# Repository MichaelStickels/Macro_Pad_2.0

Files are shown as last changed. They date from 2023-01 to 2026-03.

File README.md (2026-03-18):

# Macro Pad 2.0

DIY custom macro keypad and [Deej](https://github.com/omriharel/deej) volume control board with RGB based on the Seeed Studio XIAO RP2040 and CircuitPython.

<div align="center">
  <kbd>
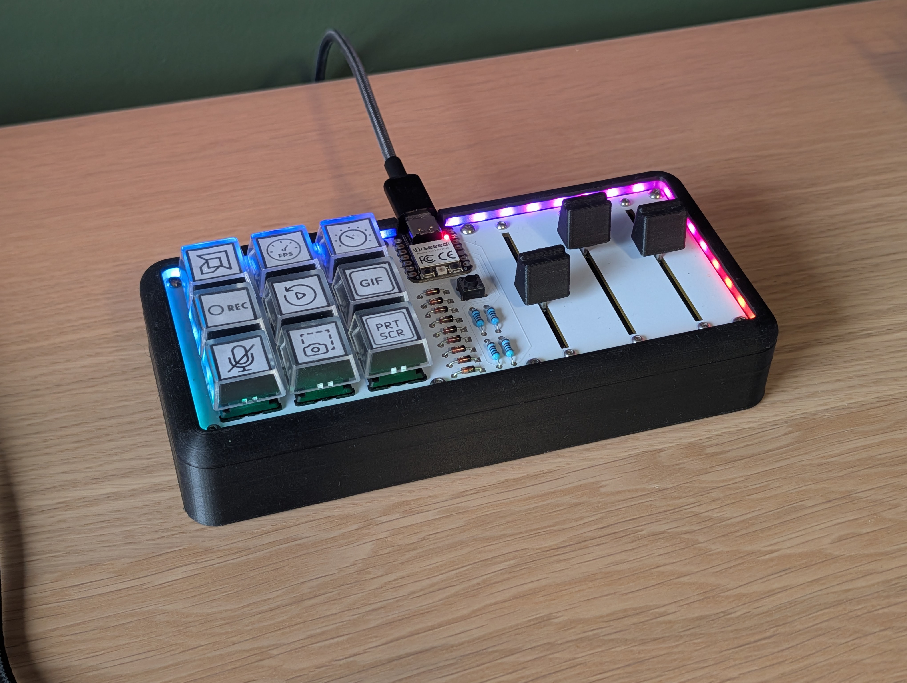
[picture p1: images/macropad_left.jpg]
    
  </kbd>
</div>

## Description

After really enjoying my [first DIY macro keypad](https://github.com/MichaelStickels/Macro_Keypad), I set out to create a second iteration of my own unique design that incorporated even more features. Mainly, I wanted to combine custom macro functionality with slide potentiometers for per-app volume control with Deej. This macro pad prioritizes looks rather than targeting the lowest cost or easiest assembly. The keyswitches are frame-mounted through the PCB so require hand wiring on the back, and the special side lit LED strip for the RGB is a bit spendy. But I am very happy with how it turned out, and it looks great on my desk.

### Features

- 9 fully programmable custom macro keys
- 3 volume sliders for use with Deej
- Fully customizable RGB and onboard button
- Easily change settings with almost any text editor
- USB C interface
- Mechanical keyswitches
- No driver needed
- Open source

### Built with

- CircuitPython
- Adafruit NeoPixel
- Adafruit MatrixKeypad
- Deej
- Love

## Photos

Some more photos of the project and the build process.

<div align="center">
  <kbd>
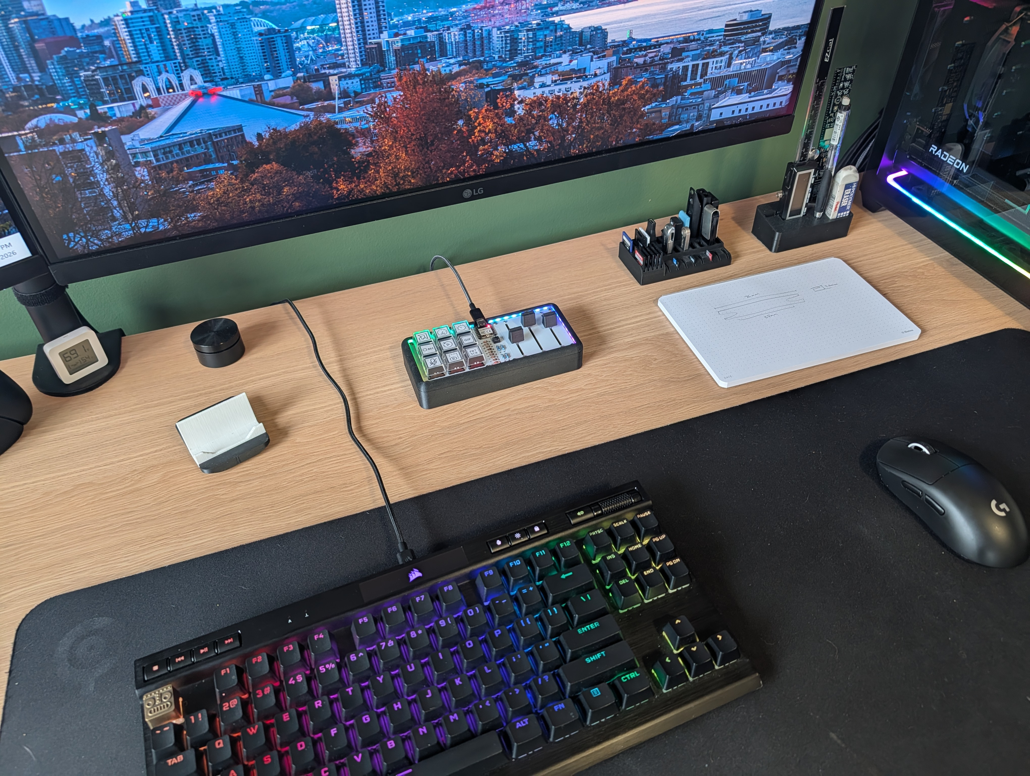
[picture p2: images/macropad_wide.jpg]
    
  </kbd>
 <!--  caption of what is in this photo -->
</div>

<div align="center">
  <kbd>
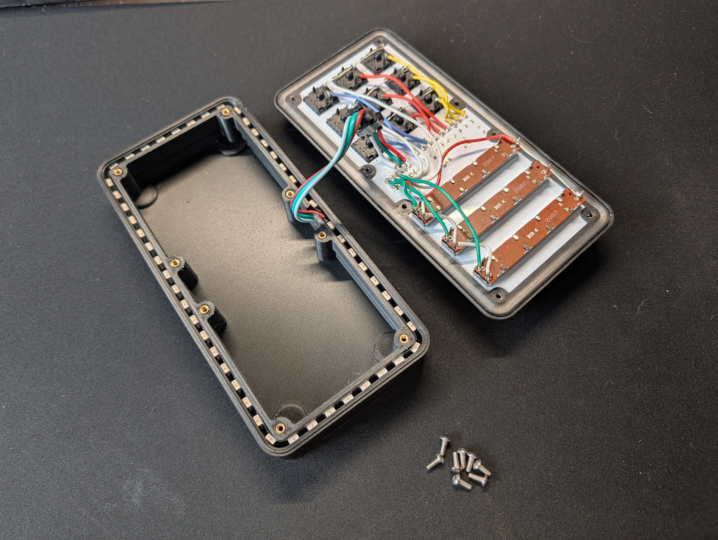
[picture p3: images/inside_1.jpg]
    
  </kbd>
 <!--  caption of what is in this photo -->
</div>

<div align="center">
  <kbd>
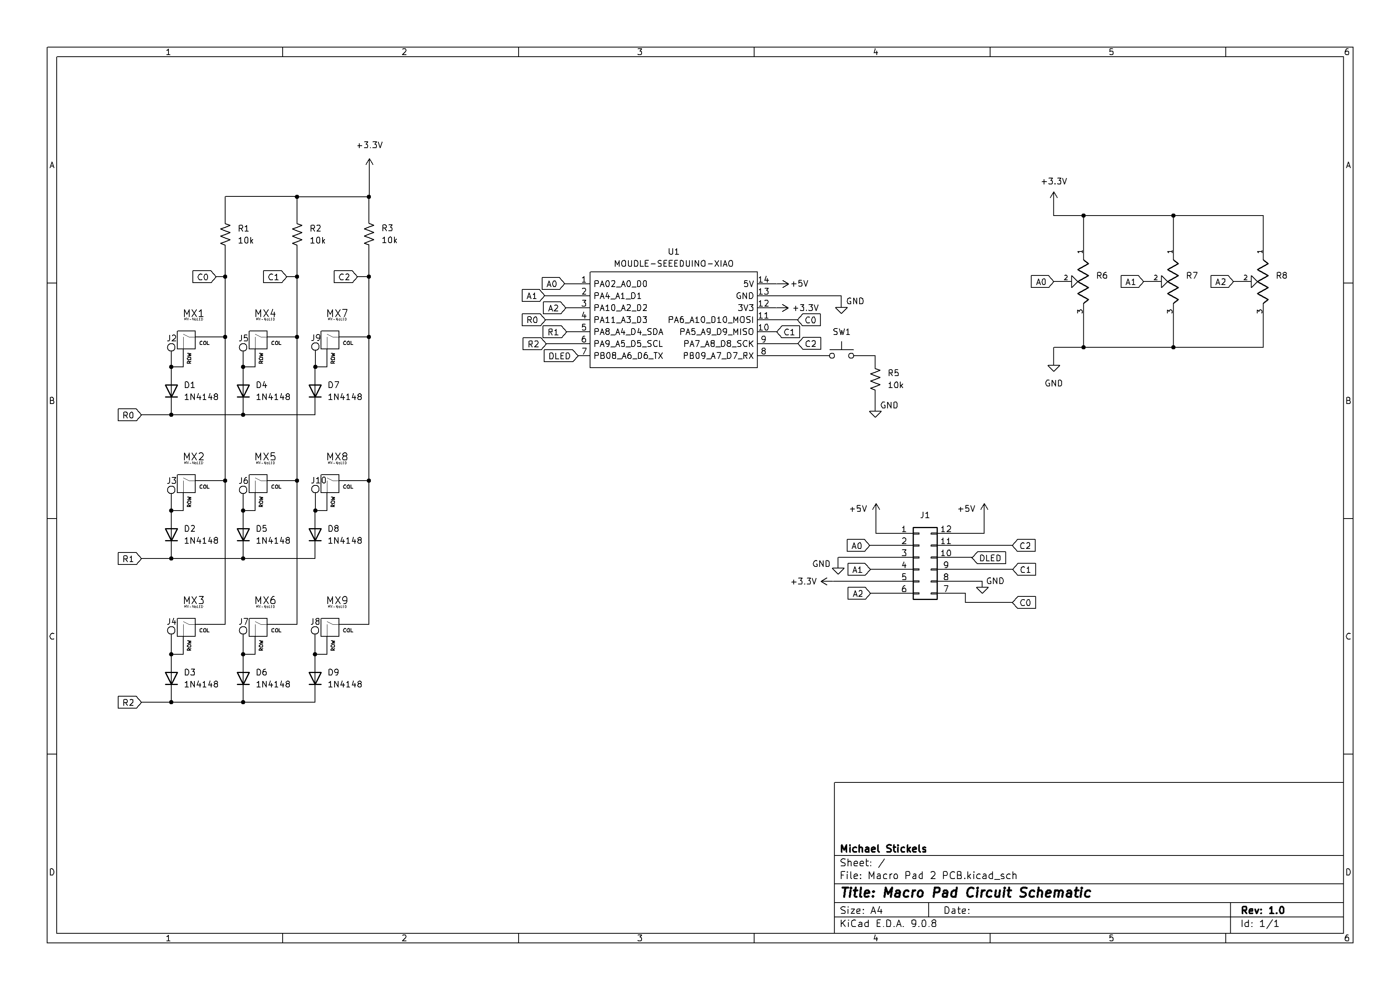
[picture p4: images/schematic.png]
    
  </kbd>
 <!--  caption of what is in this photo -->
</div>

## Building One Yourself

#### Here's what you'll need:
1. Custom PCB from an online supplier
2. 3D printed case
3. All parts listed on the BOM below
4. One USB-C cable
5. Basic soldering tools

### Custom PCB

PCB Gerber files are included in the release. Simply upload the whole .zip to the custom PCB manufacturer of your choice to order one for yourself (like JLPCB). This project only needs a very basic 2 layer PCB, I recommend white to show off the RGB. Make sure you choose the 'remove mark' or equivilent option to make sure they don't print an order number on the front fo your PCBs.

### 3D Printed Case

The case top uses translucent filament as a light pipe for the LEDs. At this revision, the design requires a multi-material printer. If you don't want to implement the RGB, you can print it all in one color on almost any printer. STL, 3MF, and F3D files are included for all parts.
<div align="center">
  <kbd>
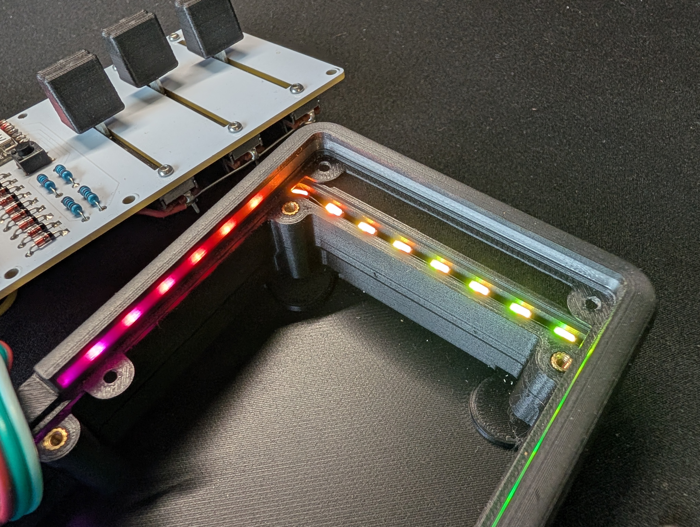
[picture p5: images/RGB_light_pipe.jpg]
    
  </kbd>
 <!--  caption of what is in this photo -->
</div>

### Bill Of Materials  
[Here](https://www.digikey.com/short/9nwmrv4t) is a DigiKey cart with all electronic components ready to order.

| Quantity | Item | DigiKey Link |
|---|---|---|
| 1 | MacroPad PCB | |
| 1 | Seeed Studio XIAO RP2040 | [1597-102010428-ND](https://www.digikey.com/en/products/detail/seeed-technology-co-ltd/102010428/14672129) |
| 9 | Cherry MX Style Keyswitches | [CH196-ND](https://www.digikey.com/en/products/detail/cherry-americas-llc/MX1A-E1NN/40084) |
| 9 | Keycaps | [1528-5662-ND](https://www.digikey.com/en/products/detail/adafruit-industries-llc/5662/18716469) |
| 3 | 45mm 10k Slide Potentiometers | [PTA4553-2015CPB103-ND](https://www.digikey.com/en/products/detail/bourns-inc/PTA4553-2015CPB103/3781213) |
| 1 | 6x6mm Tactile Push Button | [450-1650-ND](https://www.digikey.com/en/products/detail/te-connectivity-alcoswitch-switches/1825910-6/1632536) |
| 4 | 10kΩ Resistors | [MFP-25BRD52-10K](https://www.digikey.com/en/products/detail/yageo/MFP-25BRD52-10K/2058797) |
| 9 | 1N4148 Diodes | [1N4148FS-ND](https://www.digikey.com/en/products/detail/onsemi/1N4148/458603) |
| 1 | Side Lit 5v RGB LED Strip | [1528-2499-ND](https://www.digikey.com/en/products/detail/adafruit-industries-llc/3634/8019479) |
| 1 | 3D Printed Case | |
| 8 | M2.5 Screws | |
| 8 | M2.5 Heat-set Inserts | |
| 6 | M2 Screws (to mount pots) | |
| | Some small wire for hand soldering keyswitches | |

### Assembly

Solder the RP2040, resistors, diodes, and button to the front of the board. 3D-printable bend guides are included to get clean consistent shapes on all the diodes and resistors.

Then install the keyswitches and pots, and flip it over to hand wire the back.
The PCB features labeled pads on the back to connect the keyswitches, potentiometers, and RGB strip. Hand wiring these is a little tricky but results in a very clean look on the front.
<div align="center">
  <kbd>
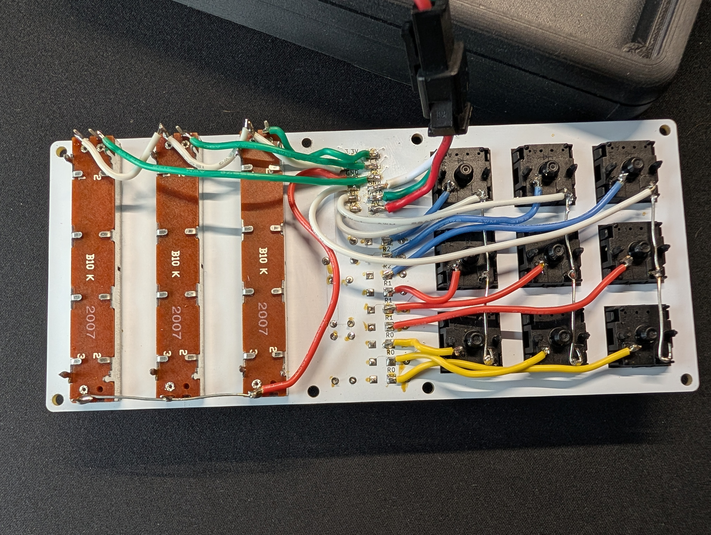
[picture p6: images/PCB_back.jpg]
    
  </kbd>
 <!--  caption of what is in this photo -->
</div>

### Software

Once soldered up, install the [CircuitPython bootloader](https://circuitpython.org/board/seeeduino_xiao_rp2040/) onto the RP2040 using [these instructions](https://wiki.seeedstudio.com/XIAO-RP2040-with-CircuitPython/).

Then copy the entire contents of the firmware folder to the CIRCUITPYTHON drive. This includes the example configuration and the necessary external libraries.

Press the reset button or unplug and replug the RP2040 and your Macro Pad will be up and running!

For the volume sliders to work you will need to install and configure [Deej](https://github.com/omriharel/deej) using [these instructions](https://github.com/omriharel/deej?tab=readme-ov-file#how-to-run). My Deej config.yaml is included as an example.

### Configure

The Macro Pad can be easily configured using any text editor, including Notepad.

To keep your file explorer tidy, the Macro Pad does not show up as a storage device by default. To access the drive, hold the 6x6mm pushbutton down while the board boots (either by pressing the reset button or while plugging in).

It will show up on your computer as a new storage drive named MACROPAD. To configure the Pad, edit conig.py in your favorite text editor. In config.py you can edit the macro for each of the 9 keyswitches as well as the RGB mode, color, and brightness. More detailed instructions are in the file.

### Usage

WIP

### Troubleshooting

WIP

## Back matter

### Acknowledgements

Inspiration from the following projects:
* [ocreeb-12](https://github.com/sb-ocr/ocreeb-12/tree/main)
* [DuckyPad](https://github.com/dekuNukem/duckyPad)

README adapted from [TINY README](https://gist.github.com/noperator/4eba8fae61a23dc6cb1fa8fbb9122d45)

Huge shout-out to the [Deej](https://github.com/omriharel/deej) project, it's an awesome piece of software.

### See also

- [Getting Started with Seeed Studio XIAO RP2040](https://wiki.seeedstudio.com/XIAO-RP2040/)
- My first [Macro Keypad](https://github.com/MichaelStickels/Macro_Keypad)

### To-do

- [x] Implement Deej serial sender in CircuitPython
- [x] Implement configuration file
- [x] Test and refine 3D printed enclosure
- [x] Implement configurable RGB
- [ ] Implement push button to do... something?
- [ ] Expand built-in RGB options
- [ ] Revise case to work on single material printers
- [ ] DIY dye sublimation keycaps
- [ ] Create and publish Deej library for CircuitPython

### License

This project is licensed under the [GPL-3.0 License](LICENSE.md).

### Support

Like what I do?  
<a href="https://www.buymeacoffee.com/michaelstickels" target="_blank">Buy Me A Coffee</a>

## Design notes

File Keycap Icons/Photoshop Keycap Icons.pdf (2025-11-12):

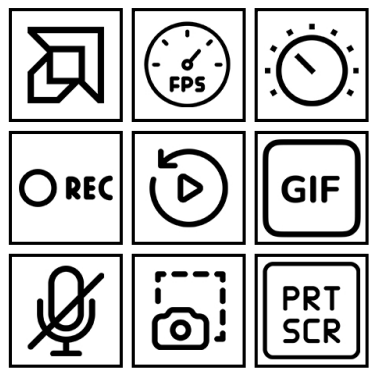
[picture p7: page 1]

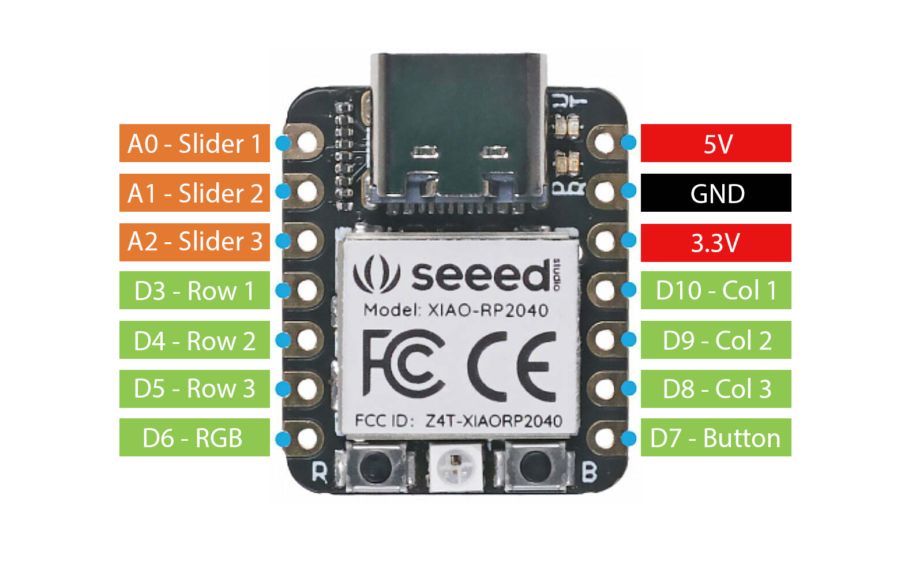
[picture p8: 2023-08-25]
images/pinout.png

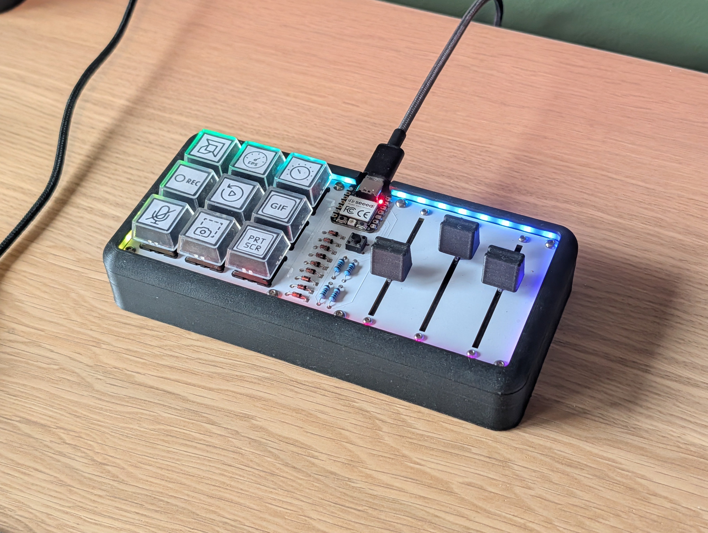
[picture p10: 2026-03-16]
images/macropad_right.jpg

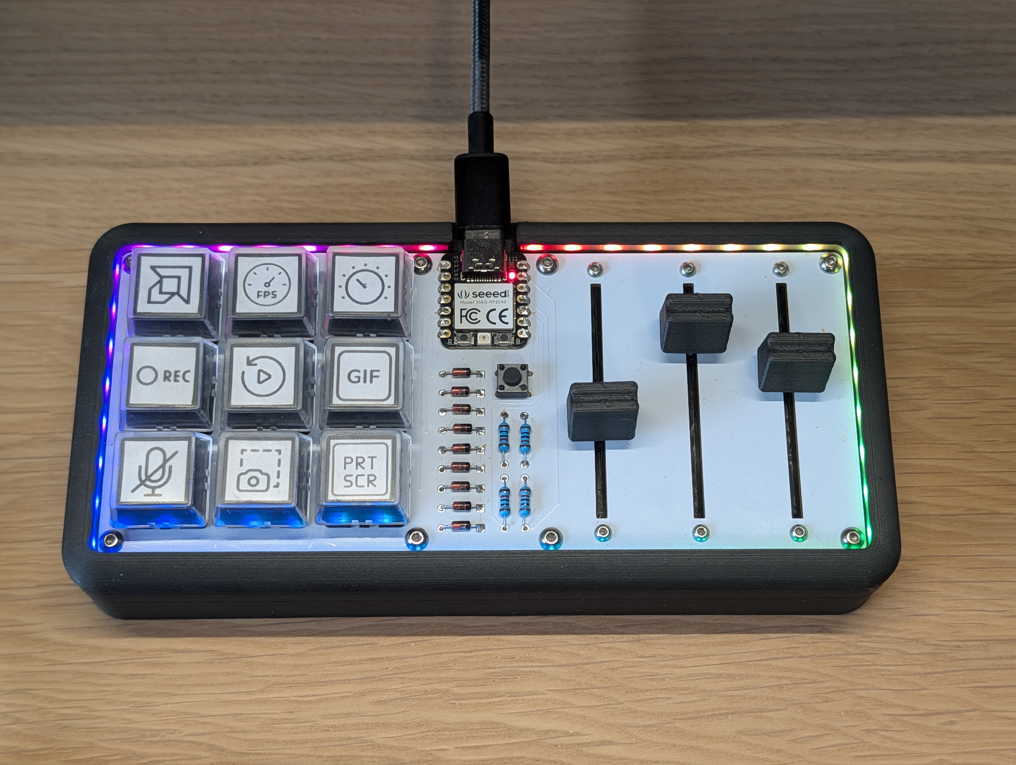
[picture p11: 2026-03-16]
images/macropad_top.jpg

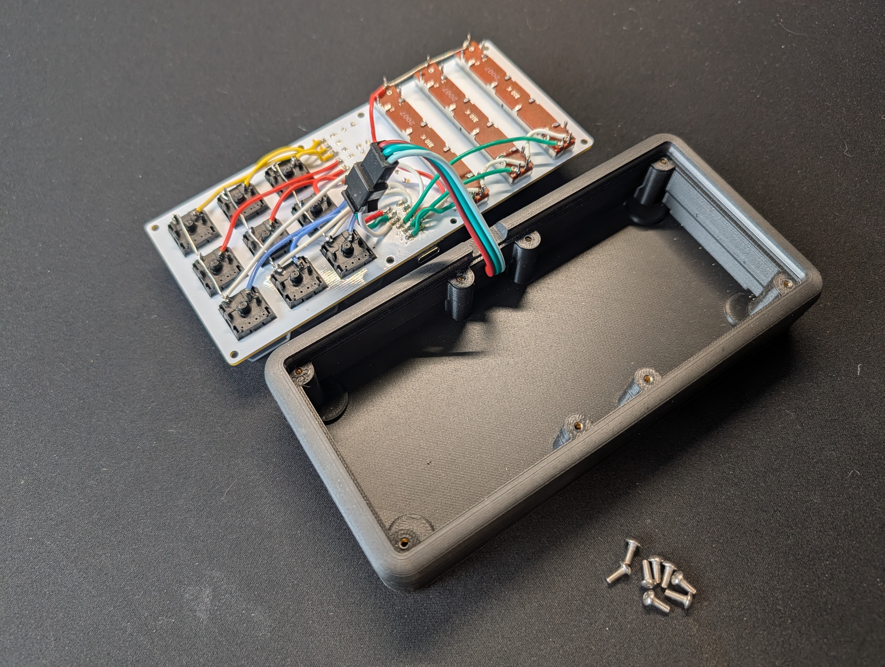
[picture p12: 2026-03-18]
images/inside_2.jpg

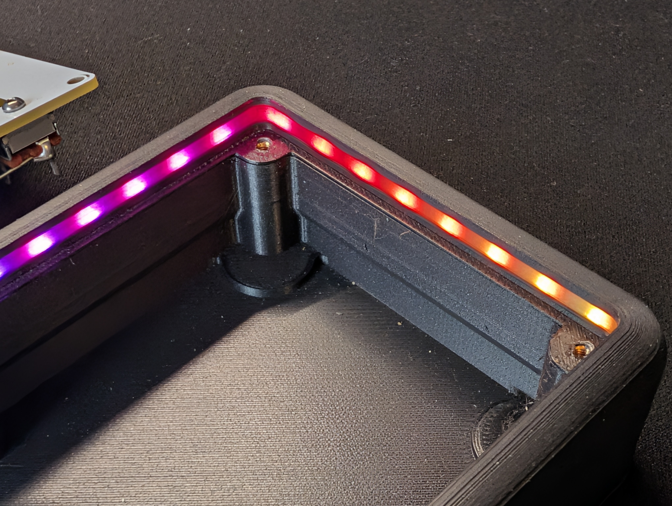
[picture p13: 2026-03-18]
images/RGB_closeup.jpg

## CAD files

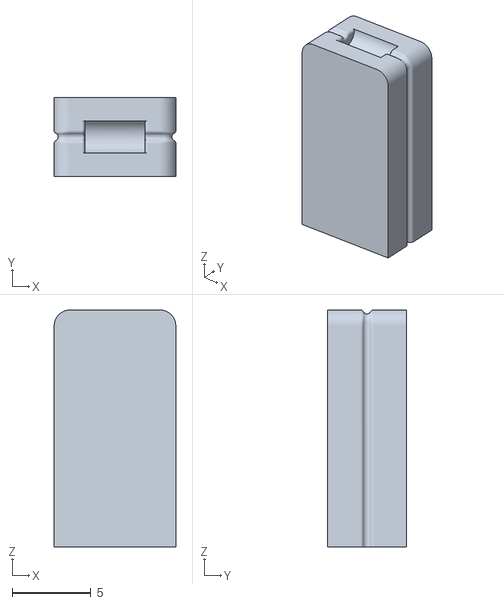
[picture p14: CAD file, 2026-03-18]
3D Print Files/Diode Bend Guide.stl
7.70 x 5.00 x 15.0

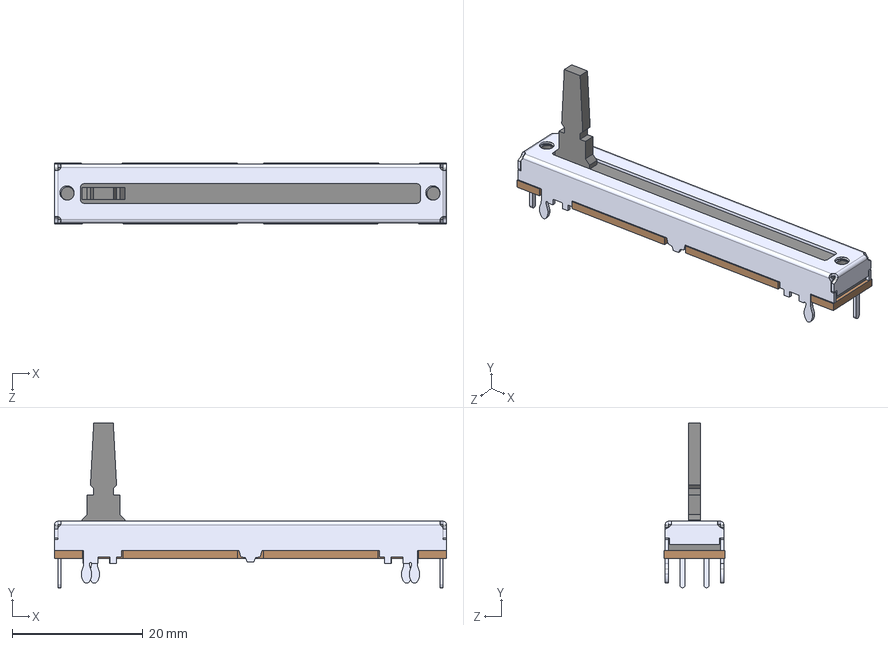
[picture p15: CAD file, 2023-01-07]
KiCad/Project Libraries/Slide Potentiometer/PTA4543-2015DPB103.step
60.0 x 25.2 x 9.40 mm

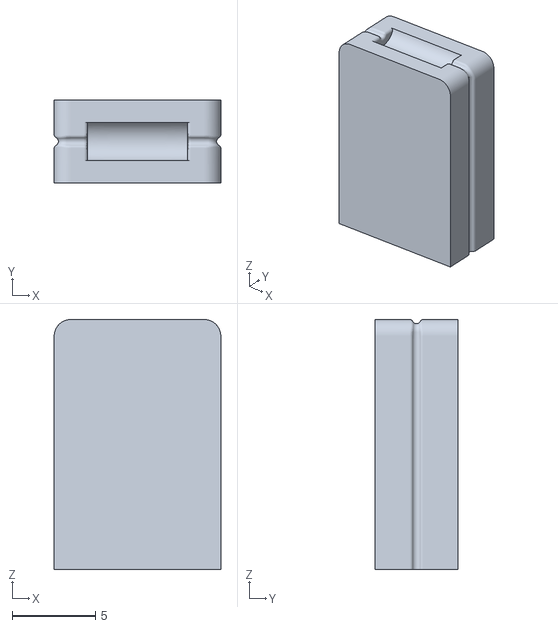
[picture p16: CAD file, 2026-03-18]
3D Print Files/Resistor Bend Guide.stl
10.0 x 5.00 x 15.0

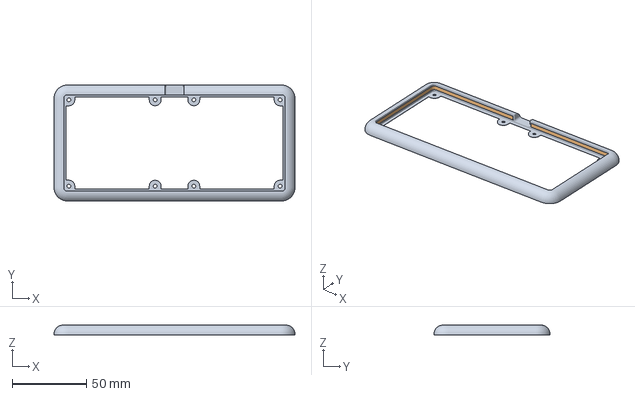
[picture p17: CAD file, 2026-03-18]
3D Print Files/Case Top Combined.3mf
162.0 x 78.0 x 6.60 mm

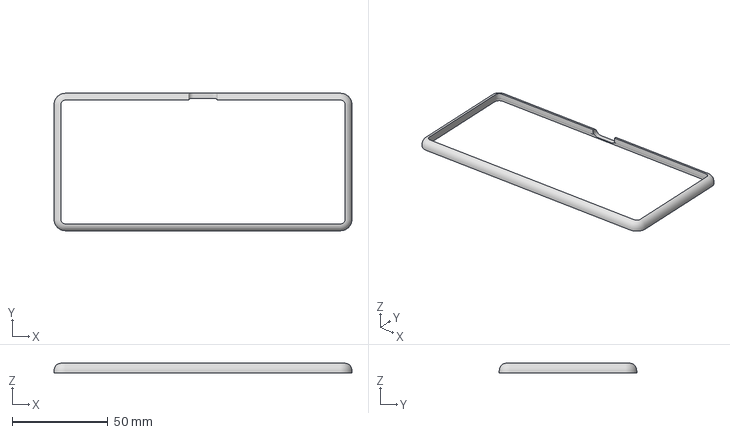
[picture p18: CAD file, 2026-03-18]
3D Print Files/Case Top Clear Component.3mf
156.0 x 72.0 x 5.00 mm

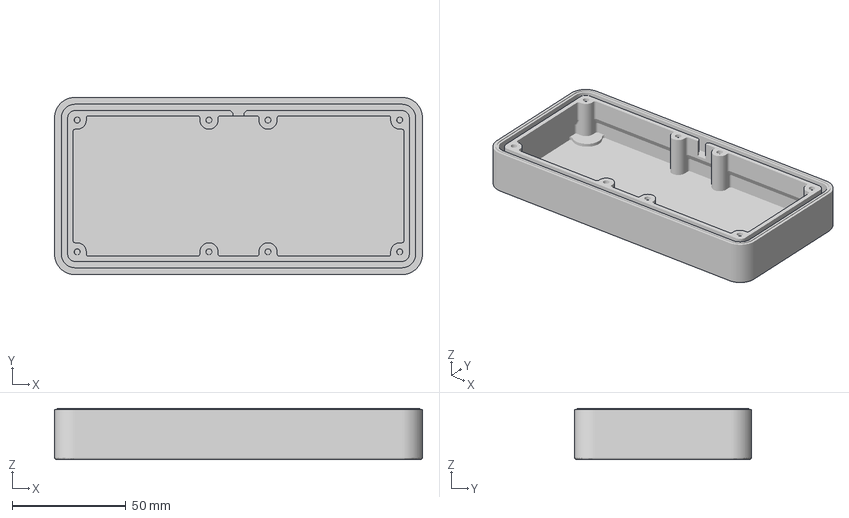
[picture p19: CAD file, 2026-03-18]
3D Print Files/Case Bottom.3mf
162.0 x 78.0 x 22.6 mm

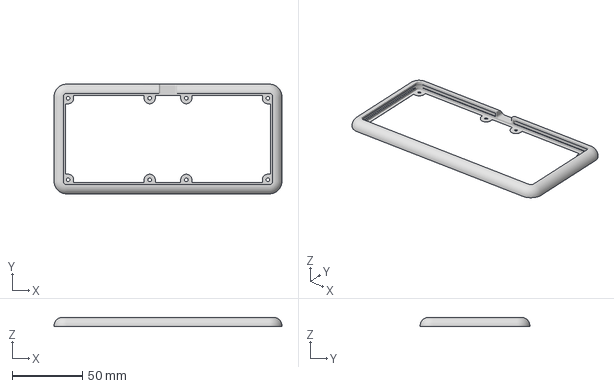
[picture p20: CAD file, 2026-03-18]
3D Print Files/Case Top Black Component.3mf
162.0 x 78.0 x 6.60 mm

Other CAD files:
3D Print Files/Case Bottom.f3d
3D Print Files/Case Bottom.stl
3D Print Files/Case Top Black Component.stl
3D Print Files/Case Top Clear Component.stl
3D Print Files/Case Top Combined.stl
3D Print Files/Case Top.f3d

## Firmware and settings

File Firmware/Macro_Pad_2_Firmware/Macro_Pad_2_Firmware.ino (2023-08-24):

/*

  Macro_Keypad_2.0 Firmware

  Michael Stickels
  
  Last Updated: *#*#*#*#

  GPL-3.0 License

*/


// Import Libraries
#include <Keypad_Matrix.h>
//#include <Keyboard.h>
//#include <Adafruit_NeoPixel.h>
//#include <AceButton.h>


// Deej setup
const int NUM_SLIDERS = 3;
const int analogInputs[NUM_SLIDERS] = {7, 8, 9};
int analogSliderValues[NUM_SLIDERS];
float coefficient;


// Keypad matrix setup
const byte ROWS = 3;
const byte COLS = 3;
const char keys[ROWS][COLS] = { {'1','2','3'},
                                {'4','5','6'},
                                {'7','8','9'}};
const byte rowPins[ROWS] = {4, 5, 6};
const byte colPins[COLS] = {0, 1, 2};
Keypad_Matrix keypad = Keypad_Matrix( makeKeymap (keys), rowPins, colPins, ROWS, COLS );


// Button setup
const int buttonPin = 10;


// RGB setup
#define DATA_PIN      10
#define PIXEL_COUNT   16



// =====================

//
void setup() { 

  // 10s delay for interrupting setup with programming if needed
  delay(10000);

  
  // Initiate Deej
  for (int i = 0; i < NUM_SLIDERS; i++) {
    pinMode(analogInputs[i], INPUT);
  }
  Serial.begin(9600);
  coefficient = 1023 / pow(1023, 2);  // For Deej adjustment function


  // Initiate keypad matrix and HID keyboard
  keypad.begin ();
  keypad.setKeyDownHandler (keyDown);
  keypad.setKeyUpHandler   (keyUp);
//  Keyboard.begin();


  // Initiate button
//  AceButton button(BUTTON_PIN);
//  pinMode(BUTTON_PIN, INPUT);
//  ButtonConfig* buttonConfig = button.getButtonConfig();
//  buttonConfig->setEventHandler(handleEvent);
//  buttonConfig->setFeature(ButtonConfig::kFeatureClick);        // enable short and long single click
//  buttonConfig->setFeature(ButtonConfig::kFeatureLongPress);


  // Initiate RGB
//  Adafruit_NeoPixel strip(PIXEL_COUNT, PIXEL_PIN, NEO_GRB + NEO_KHZ800);
//  strip.begin();
//  strip.show();
  
}

//
void loop() {

  // Deej tick
  updateSliderValues();
  sendSliderValues();


  // Keypad tick
  keypad.scan ();


  // Button tick
//  button.check();


  // RGB tick

  
  delay(10);
  
}



// =====================
// Deej helper functions

// Exponential function to adjust potentiometer input for more
// immediate adjustment in top end of volume
int valueFunction(int value) {
  return round(coefficient * pow(value - 1023,2));
}

// Default Deej update function
void updateSliderValues() {
  for (int i = 0; i < NUM_SLIDERS; i++) {
     analogSliderValues[i] = analogRead(analogInputs[i]);
  }
}

// Default deej send function
void sendSliderValues() {
  String builtString = String("");

  for (int i = 0; i < NUM_SLIDERS; i++) {
    builtString += String((int)analogSliderValues[i]);

    if (i < NUM_SLIDERS - 1) {
      builtString += String("|");
    }
  }
  
  Serial.println(builtString);
}



// =====================
// Keypad helper functions

// Handler for keys pressed down
void keyDown (const char which)
{
//  switch (which) {
//
//  // Key 1 press
//  case '1':
//    Keyboard.press(KEY1);
//    break;
//
//  // Key 2 press
//  case '2':
//    Keyboard.press(KEY2);
//    break;
//
//  // Key 3 press
//  case '3':
//    Keyboard.press(KEY3);
//    break;
//
//  // Key 4 press
//  case '4':
//    Keyboard.press(KEY4);
//    break;
//
//  // Key 5 press
//  case '5':
//    Keyboard.press(ALT);
//    Keyboard.press(KEY5);
//    break;
//
//   case '6':
//   // Key 6 press
//    Keyboard.press(KEY_LEFT_CTRL);
//    Keyboard.press(KEY_LEFT_ALT);
//    Keyboard.press(206); // print screen
//    break;
//
//  case '7':
//  // Key 7 press
//    Keyboard.press(KEY_LEFT_ALT);
//    Keyboard.press(KEY7);
//    break;
//
//  // Key 8 press
//  case '8':
//    Keyboard.press(KEY8);
//    break;
//  }
}

// Handler for keys pressed up
void keyUp (const char which)
{
  // Currently unused
}



// =====================
// Button helper functions

// comment
//void handleEvent(AceButton* /* button */, uint8_t eventType, uint8_t buttonState) {
//
//  switch (eventType) {
//    case AceButton::kEventPressed:      // short press
//      // cycle LED brightness/off
//      break;
//    case AceButton::kEventLongPressed:  // long press
//      // change LED mode
//      break;
//  }
//}



// =====================

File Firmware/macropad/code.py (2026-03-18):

"""

    Macro_Keypad_2.0 Firmware

    Created by Michael Stickels

    Last Updated: *Unreleased*

    GPL-3.0 License


"""

import config
import adafruit_matrixkeypad
import supervisor
import board
import time
import usb_hid
import neopixel
from analogio import AnalogIn
from digitalio import DigitalInOut
from adafruit_hid.keyboard import Keyboard
from adafruit_hid.keycode import Keycode
from rainbowio import colorwheel


# Pin assignments (preset for Xiao RP2040)
KEY_COL_1 = board.D10
KEY_COL_2 = board.D9
KEY_COL_3 = board.D8
KEY_ROW_1 = board.D5
KEY_ROW_2 = board.D4
KEY_ROW_3 = board.D3
SLIDER_1 = board.A0
SLIDER_2 = board.A1
SLIDER_3 = board.A2
RGB_DATA = board.D6
BUTTON = board.D7

# Initializations ------------------------------------------------------------

# Setup and initialize 3x3 matrix keypad
cols = [DigitalInOut(x) for x in (KEY_COL_1, KEY_COL_2, KEY_COL_3)]
rows = [DigitalInOut(x) for x in (KEY_ROW_1, KEY_ROW_2, KEY_ROW_3)]
keys = ((1, 2, 3), (4, 5, 6), (7, 8, 9))
keypad = adafruit_matrixkeypad.Matrix_Keypad(rows, cols, keys)
last_pressed = []

# Initialize HID keyboard input
time.sleep(1)  # Sleep for a moment to avoid a race condition on some systems (according to Adafruit)
kbd = Keyboard(usb_hid.devices)

# Initialize Deej sliders
slider_pins = [AnalogIn(SLIDER_1), AnalogIn(SLIDER_2), AnalogIn(SLIDER_3)]

# Initialize RGB
pixel_pin = RGB_DATA
num_pixels = 51
RGB_brightness = config.RGB_brightness
RGB_mode = config.RGB_mode
RGB_color = config.RGB_color
off = (0,0,0)
RGB_tick = 0
pixels = neopixel.NeoPixel(pixel_pin, num_pixels, brightness = RGB_brightness, auto_write = False)


# Helper Functions  ----------------------------------------------------------

# Keyboard input helper
def send_keys(x):
    if x == 1:
        for key in config.MACRO_1:
            kbd.press(key)
        kbd.release_all()
    elif x == 2:
        for key in config.MACRO_2:
            kbd.press(key)
        kbd.release_all()
    elif x == 3:
        for key in config.MACRO_3:
            kbd.press(key)
        kbd.release_all()
    elif x == 4:
        for key in config.MACRO_4:
            kbd.press(key)
        kbd.release_all()   
    elif x == 5:
        for key in config.MACRO_5:
            kbd.press(key)
        kbd.release_all()
    elif x == 6:
        for key in config.MACRO_6:
            kbd.press(key)
        kbd.release_all()
    elif x == 7:
        for key in config.MACRO_7:
            kbd.press(key)
        kbd.release_all()
    elif x == 8:
        for key in config.MACRO_8:
            kbd.press(key)
        kbd.release_all()
    elif x == 9:
        for key in config.MACRO_9:
            kbd.press(key)
        kbd.release_all()


# Deej Helper
# Adjusts response of linear potentiometers for finer low volume control
def get_voltage(pin):
    return round((1023 / 1023 ** 2) * pow(pin.value * 1023 / 65535 - 1023, 2))


# Rainbow RGB Helper
def rainbow_update(j):
    for i in range(num_pixels):
        rc_index = (i * 256 // num_pixels) + j
        pixels[i] = colorwheel(rc_index & 255)
    pixels.show()


# Running loop ------------------------------------------------------------
while True:

    # Do functions only if USB connection is active
    if supervisor.runtime.usb_connected:    # checks USB connection

        # Keypad handler
        keys = keypad.pressed_keys
        if keys:                                # If any keys are pressed
            temp = []
            for element in keys:
                if element not in last_pressed:
                    temp.append(element)        # and any of those keys are newly pressed
            if len(temp) > 0:
                send_keys(temp[0])              # send input to computer.
        last_pressed = keys                     # Stops keys from repeating while held down.

        # Deej handler
        print_string = ""
        for pin in slider_pins:                     # read value of each slider
            print_string += str(get_voltage(pin))
            if pin != slider_pins[-1]:              # put into Deej format
                print_string += "|"
        print(print_string)                         # send to computer over serial

        # RGB update
        if RGB_mode == 'rainbow':
            if RGB_tick >= 256: RGB_tick = 0
            rainbow_update(RGB_tick)
            RGB_tick += 2
        else:
            pixels.fill(RGB_color)
            pixels.show()

    # If USB is not connected, turn off LEDs and don't bother sending data
    else:
        pixels.fill(off)
        pixels.show()
        time.sleep(5)


    # Slow the program down a smidge. There are better ways to do this, but this works for now
    time.sleep(0.1)

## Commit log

2023-01-07 Setup KiCad project, add keyboard library submodules
    [PCB.kicad_pcb, PCB.kicad_sch]
2023-01-07 Add Seeeduino library, organize directories
    [PCB.kicad_pcb, PCB.kicad_sch]
2023-01-07 Electrical Schematic
    [PCB.kicad_sch, PTA4543-2015DPB103.step]
2023-01-07 PCB Template Design
    [PCB.kicad_sch]
2023-01-07 Top PCB Development, Footprints
    [Bottom PCB.kicad_sch, PCB_Template.kicad_sch, Top PCB.kicad_sch]
2023-01-08 Split PCB into top, bottom. Develop Top
    [Top PCB.kicad_sch]
2023-01-09 Develop bottom PCB
    [Bottom PCB.kicad_sch]
2023-02-24 Restructuring PCBs to only one top PCB, handwired switches
    [Top PCB.kicad_sch]
2023-02-28 Complete design for single top PCB, change mounting holes to M3
    [Bottom PCB.kicad_pcb, Bottom PCB.kicad_sch, PCB_Template.kicad_sch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]
2023-03-14 Begin firmware, create folders
    [Top PCB-B_Cu.gbl, Top PCB-B_Mask.gbs, Top PCB-B_Paste.gbp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]
2023-03-15 Begin writing firmware, fix PCB to use 3.3V logic level
    [Top PCB-B_Cu.gbl, Top PCB-B_Mask.gbs, Top PCB-B_Paste.gbp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]
2023-08-16 Add exponential function to slider value handling for easier volume control for my ears
    [Top PCB-B_Cu.gbl, Top PCB-B_Mask.gbs, Top PCB-B_Paste.gbp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]
2023-08-24 Switch over to CircuitPython due to limitations with the XIAO and Arduino's built in keyboard library
2023-08-24 Organize old Arduino firmware files. Createe basic python Deej value sender
2023-08-24 Convert test files to circuitpython
2023-08-24 Change to diode matrix
2023-08-25 Working with button functionality. Ran out of storage on Seeeduino XIAO..... maybe change to RP2040?
2023-08-25 Make necessary changes to PCB to switch to RP2040
    [Bottom PCB.kicad_pcb, Bottom PCB.kicad_sch, Macro Pad 2 PCB.kicad_sch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]
2024-02-05 Change PCB mounting holes to M2.5, final PCB checks
    [Top PCB-B_Cu.gbl, Top PCB-B_Mask.gbs, Top PCB-B_Paste.gbp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]
2024-02-05 Generate PCB order files for new Rp2040 revision
    [Macro Pad 2 PCB-B_Cu.gbl, Macro Pad 2 PCB-B_Mask.gbs, Macro Pad 2 PCB-B_Paste.gbp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]
2024-02-05 Tweak PCB file, export for ordering
    [Macro Pad 2 PCB-B_Cu.gbl, Macro Pad 2 PCB-B_Mask.gbs, Macro Pad 2 PCB-B_Paste.gbp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]
2024-06-28 Change drive name, add functionality to turn off LED automatically when host computer shuts down
2026-03-18 Add 3D files
    [Case Bottom.3mf, Case Bottom.f3d, Case Bottom.stl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]
2026-03-18 Add combined top case files
    [Case Top Combined.3mf, Case Top Combined.stl]
2026-03-18 Add more images, polish readme
    [Diode Bend Guide.stl, Resistor Bend Guide.stl]
2026-03-18 add PCB info
2026-10-26 Remove debug prints
